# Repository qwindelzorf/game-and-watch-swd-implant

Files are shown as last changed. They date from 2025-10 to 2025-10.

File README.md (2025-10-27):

# Game & Watch SWD-Implant

A small [DAP-Link](https://github.com/ARMmbed/DAPLink) SWD programmer/debugger that fits insight a Nintendo® Game & Watch™ (2020/2021).

This is forked from [UlfWetzker/game-and-watch-swd-implant](https://github.com/UlfWetzker/game-and-watch-swd-implant), which has some issues and appears to be unmaintained.

## Mario (2020)

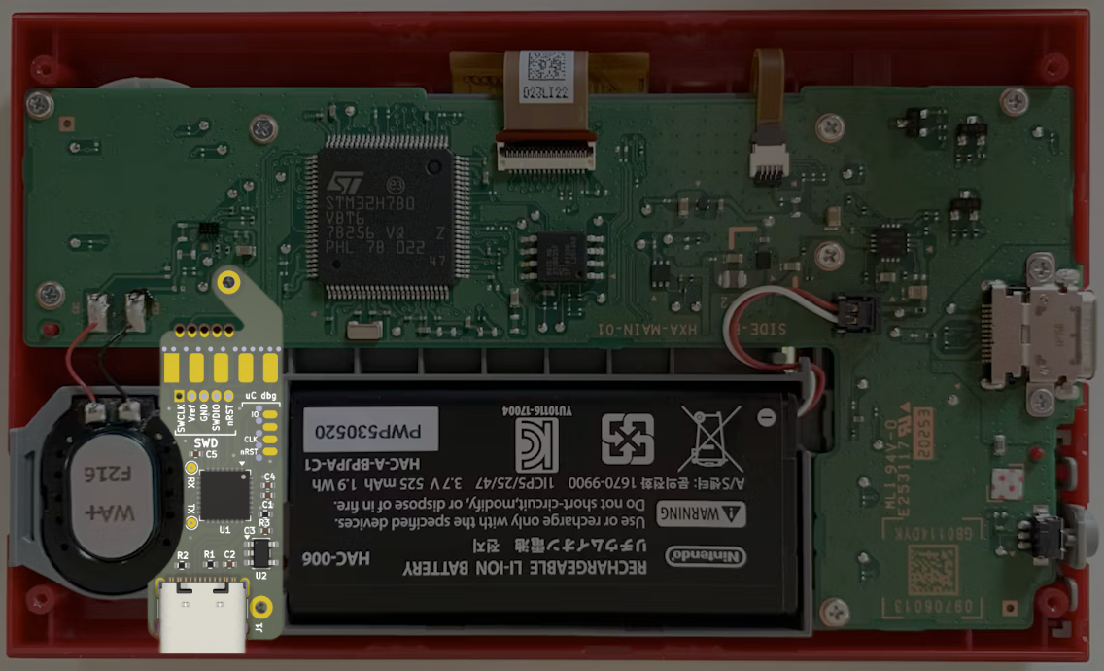
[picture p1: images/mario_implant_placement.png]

<p>
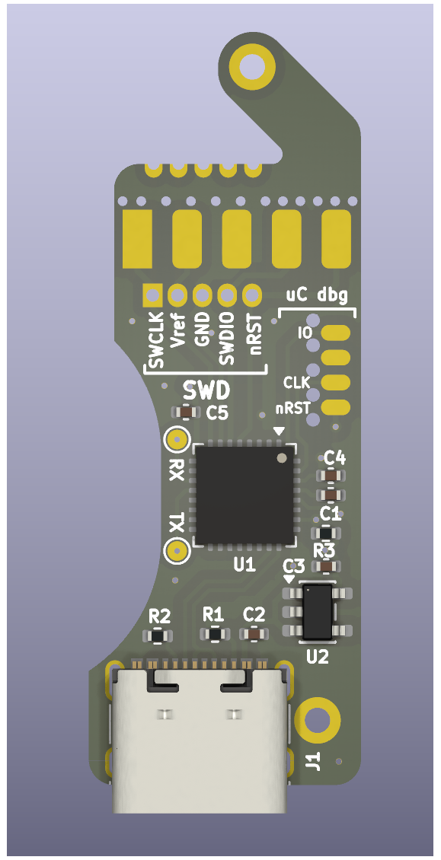
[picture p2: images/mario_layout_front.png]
Front
  
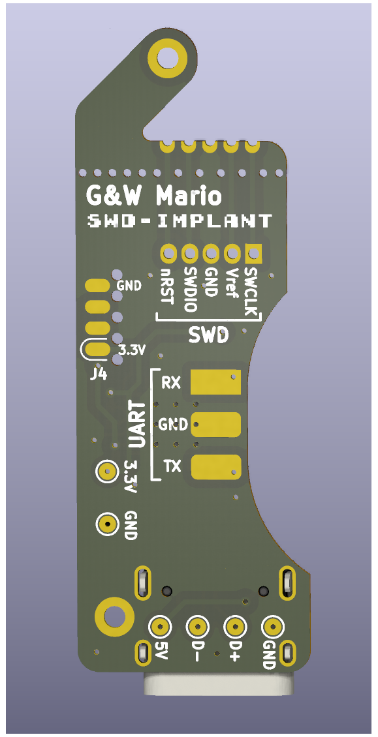
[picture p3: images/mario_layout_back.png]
Back
  
</p>

## Zelda (2021)

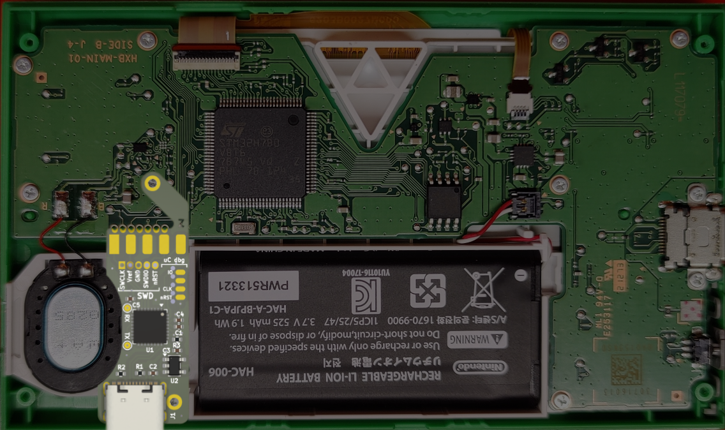
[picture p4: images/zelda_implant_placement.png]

<p>
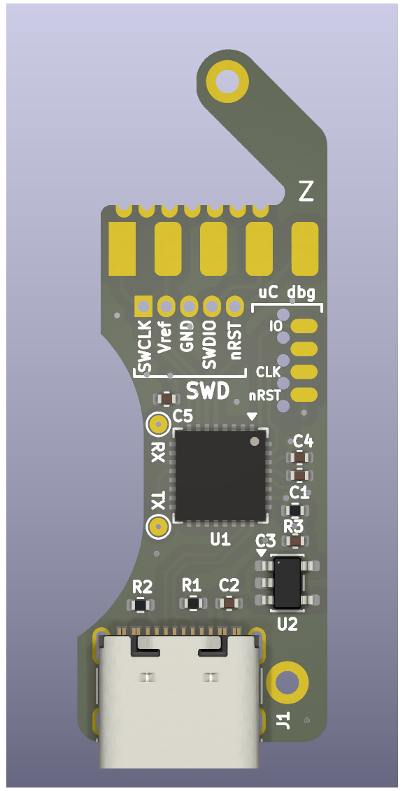
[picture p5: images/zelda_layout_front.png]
Front
  
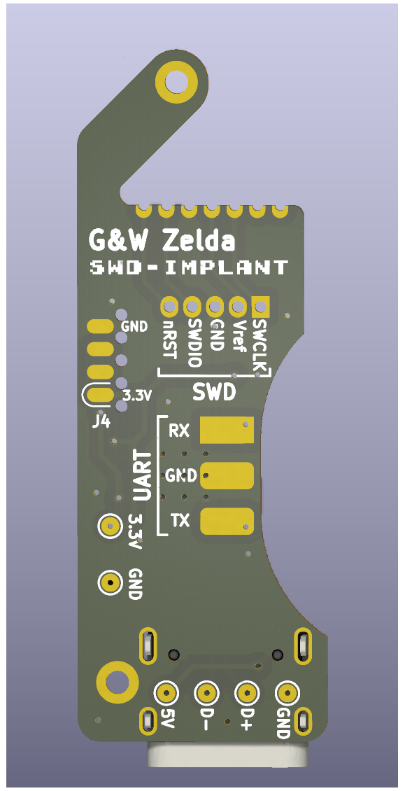
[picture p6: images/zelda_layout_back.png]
Back
  
</p>

## Implant Firmware

The implant board itself uses a [SAMD21](https://www.microchip.com/en-us/product/atsamd21g18) microcontroller, which is flashed with the [DAP-Link](https://github.com/ARMmbed/DAPLink) firmware. It is then able to act as a flasher for the G&W [STM32](https://www.st.com/en/microcontrollers-microprocessors/stm32-32-bit-arm-cortex-mcus.html) CPU. Flashing both the implant and the G&W is done using [OpenOCD](https://openocd.org/).

## G&W Firmware

The go-to firmware for these consoles is "RetroGo":
- [Original](https://github.com/kbeckmann/game-and-watch-retro-go): archived now
- [Zeus Fork](https://github.com/olderzeus/game-and-watch-retro-go): Adds more consoles
- [Sylverb Fork](https://github.com/sylverb/game-and-watch-retro-go): Adds yet more consoles, as well as support for LttP and SMW.

## Other Links

- SD Card mod: [link](https://github.com/sylverb/game-and-watch-retro-go-sd)
- Original homebrew work: [link](https://github.com/ghidraninja/game-and-watch-backup)
- Various firmware and utilities: [link](https://www.schuerewegen.tk/gnw/)
- A good tutorial on modding & flashing: [link](https://psxtools.de/forum/index.php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) (German)

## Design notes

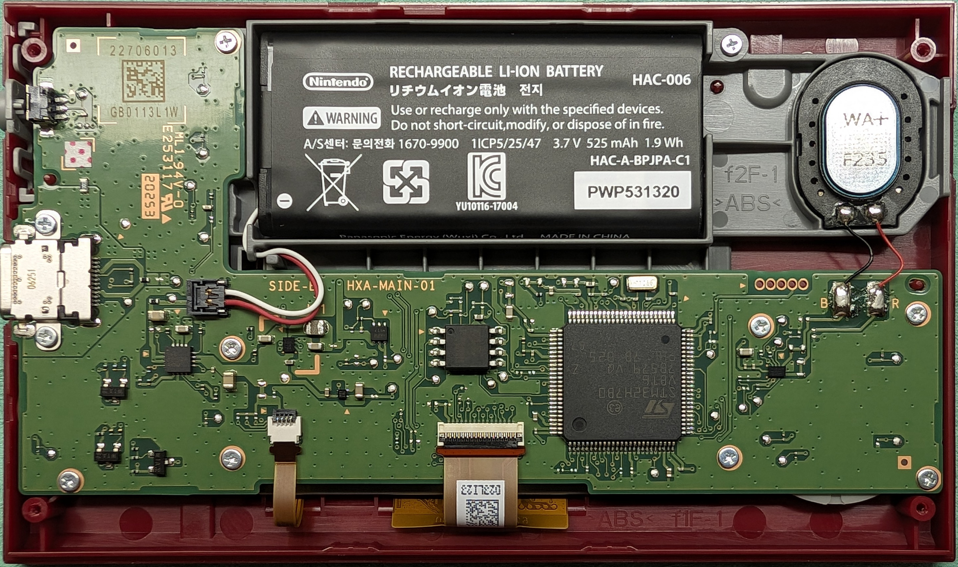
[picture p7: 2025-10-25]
images/mario_board.png

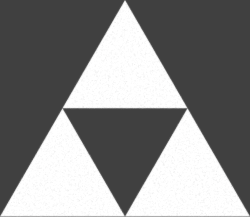
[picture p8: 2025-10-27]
triforce.png

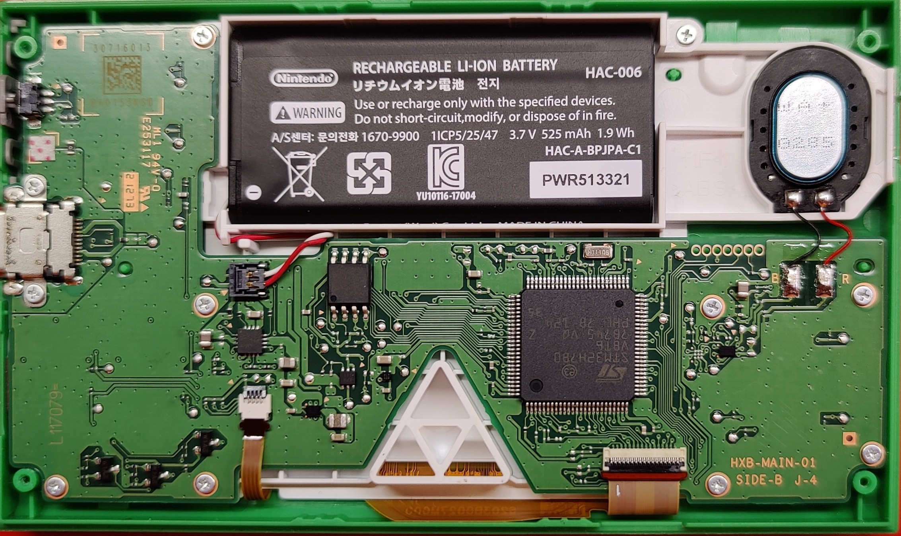
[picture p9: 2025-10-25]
images/zelda_board.png

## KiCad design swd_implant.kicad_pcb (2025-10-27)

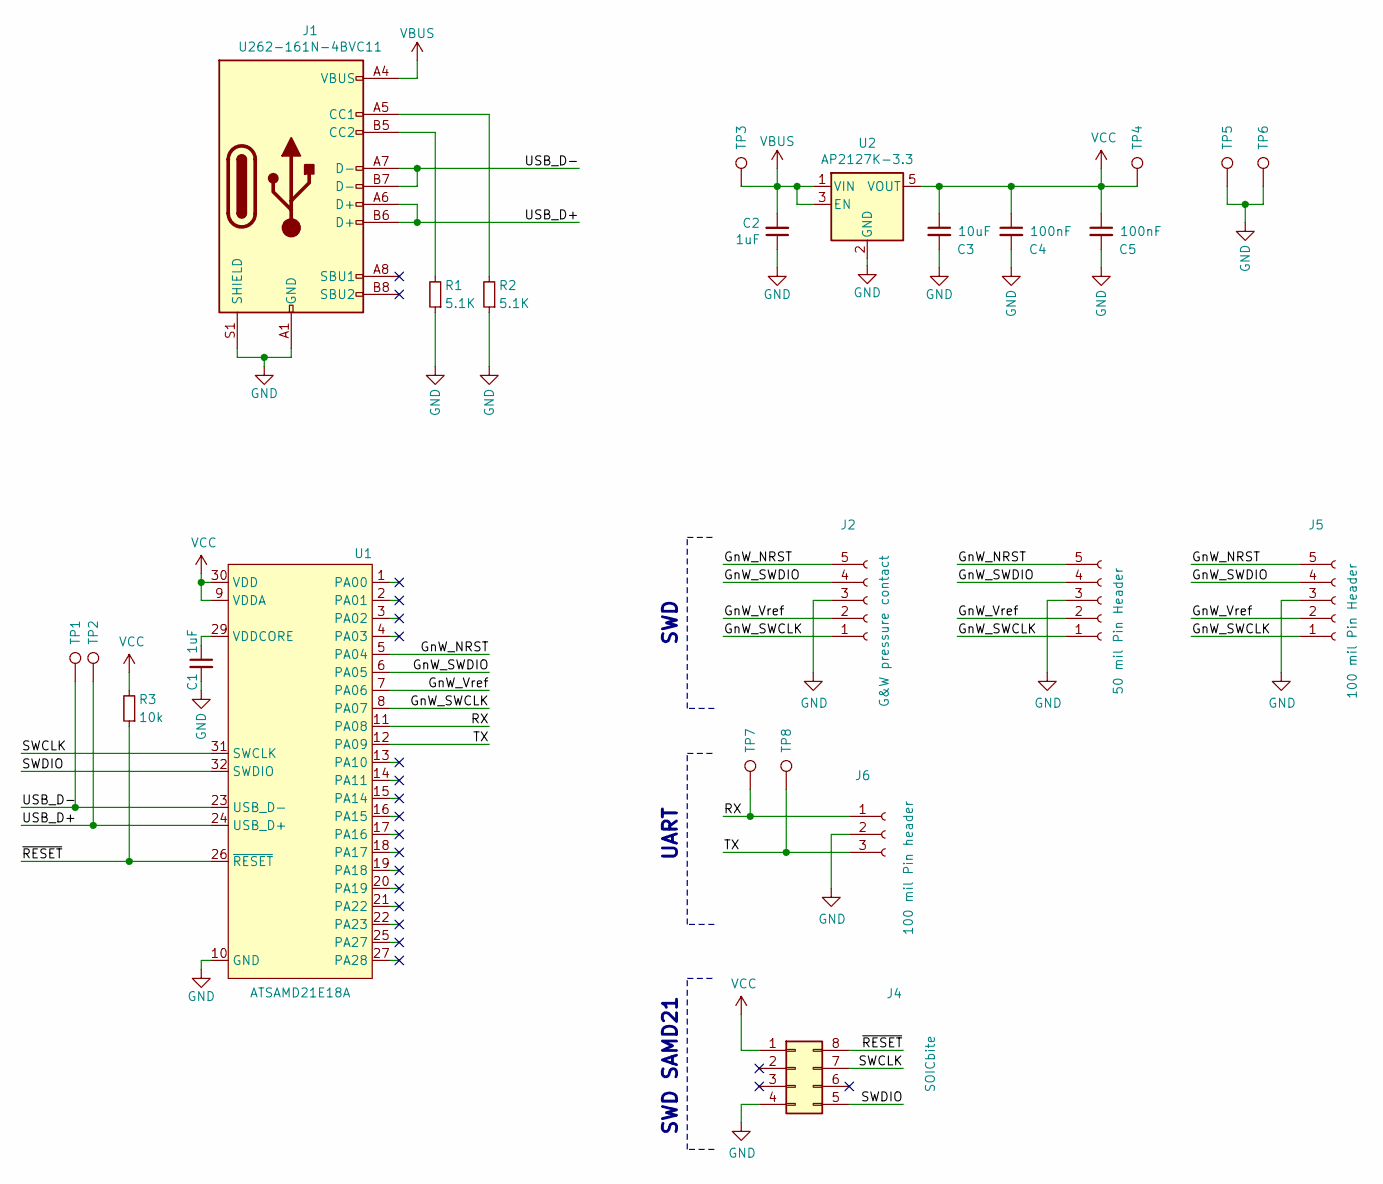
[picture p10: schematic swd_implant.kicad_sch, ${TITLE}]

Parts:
C1, C2: 1uF; C_0402_1005Metric; MFR.Part # CL05A105KA5NQNC; LCSC Part # C52923
C3: 10uF; C_0402_1005Metric; MFR.Part # CL05A106MQ5NUNC; LCSC Part # C15525
C4, C5: 100nF; C_0402_1005Metric; MFR.Part # CL05B104KO5NNNC; LCSC Part # C1525
J1: U262-161N-4BVC11; USB_C_Receptacle_XKB_U262-16XN-4BVC11; Mfr.Part # U262-161N-4BVC11; LCSC Part # C319148
J2: G&W pressure contact; GnW_SWD
J3: 50 mil Pin Header; PinHeader_1x05_P1.27mm_Vertical
J4: SOICbite; SOIC_clipProgSmall
J5: 100 mil Pin Header; PinHeader_1x05_P2.45mm_edge
J6: 100 mil Pin header; PinHeader_1x03_P2.45mm_edge
R1, R2: 5.1K; R_0402_1005Metric; MFR.Part # 0402WGF5101TCE; LCSC Part # C25905
R3: 10k; R_0402_1005Metric; MFR.Part # 0402WGJ0103TCE; LCSC Part # C25531
TP1, TP3, TP4, TP5, TP6, TP7, TP8: TP_USB_D+; TestPoint_Pad_D1.0mm
TP2: TP_USB_D-; TestPoint_Pad_D1.0mm
U1: ATSAMD21E18A; QFN-32-1EP_5x5mm_P0.5mm_EP3.6x3.6mm; MFR.Part # ATSAMD21E18A-MU; LCSC Part # C220692
U2: AP2127K-3.3; SOT-23-5; MFR.Part # AP2127K-3.3TRG1; LCSC Part # C156285

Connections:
/GnW_NRST: J2.5, J3.5, J5.5, U1.5 (PA04)
/GnW_SWCLK: J2.1, J3.1, J5.1, U1.8 (PA07)
/GnW_SWDIO: J2.4, J3.4, J5.4, U1.6 (PA05)
/GnW_Vref: J2.2, J3.2, J5.2, U1.7 (PA06)
/RX: J6.1, TP7.1, U1.11 (PA08)
/SWCLK: J4.7, U1.31 (SWCLK)
/SWDIO: J4.5, U1.32 (SWDIO)
/TX: J6.3, TP8.1, U1.12 (PA09)
/USB_D+: J1.A6 (D+), J1.B6 (D+), TP2.1, U1.24 (USB_D+)
/USB_D-: J1.A7 (D-), J1.B7 (D-), TP1.1, U1.23 (USB_D-)
/~RESET: J4.8, R3.1, U1.26 (~RESET)
GND: C1.2, C2.1, C3.2, C4.2, C5.2, J1.A1 (GND), J1.A12 (GND), J1.B1 (GND), J1.B12 (GND), J1.S1 (SHIELD), J2.3, J2.6, J2.7, J3.3, J4.4, J5.3, J6.2, R1.1, R2.1, TP5.1, TP6.1, U1.10 (GND), U1.28 (GND), U1.33, U2.2 (GND)
unnamed: J1.A5 (CC1), R2.2
unnamed: J1.B5 (CC2), R1.2
unnamed: C1.1, U1.29 (VDDCORE)
VBUS: C2.2, J1.A4 (VBUS), J1.A9 (VBUS), J1.B4 (VBUS), J1.B9 (VBUS), TP3.1, U2.1 (VIN), U2.3 (EN)
VCC: C3.1, C4.1, C5.1, J4.1, R3.2, TP4.1, U1.9 (VDDA), U1.30 (VDD), U2.5 (VOUT)

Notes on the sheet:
UART
SWD SAMD21
SWD

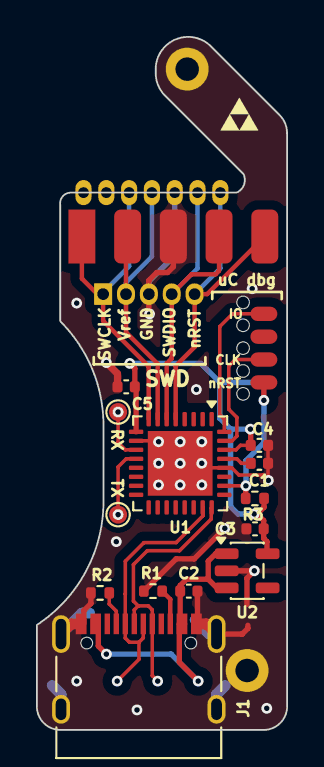
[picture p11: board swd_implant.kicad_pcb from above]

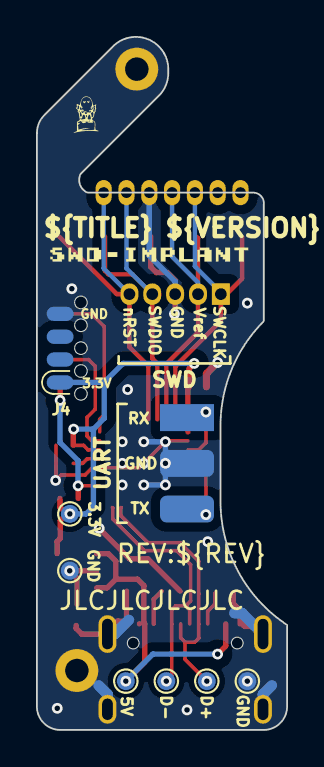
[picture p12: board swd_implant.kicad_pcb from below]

Board: 2 copper layers, 13.9 x 38.5 mm, 26 parts (10 on the bottom side), 17 nets.

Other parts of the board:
Q**: Qwindelzorf; qwindelzorf_1520
Ref**: Val**; name_logo

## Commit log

2025-10-25 New board outline & swd pinout fixes
    Changed the board outline to work with castellated edges, making it possible to
    solder down instead of just relying on pressure contact.
    Also fixed the inverted SWD pinout from upstream.
    [swd_implant.kicad_pcb, swd_implant.kicad_sch]
2025-10-25 Add Z marker to front of board
    This Z is to indicate that it is the "Zelda" variant of the implant
    board.
    [swd_implant.kicad_pcb]
2025-10-25 Add Zelda version of implant
    Just changed the board shape to fit the altered location of the SWD pins
    on that version.
    [swd_implant.kicad_pcb]
2025-10-25 Prep for fabrication
    [swd_implant.kicad_pcb, swd_implant.kicad_sch]
2025-10-26 Add LCSC part numbers
    [swd_implant.kicad_pcb, swd_implant.kicad_sch]
2025-10-27 Add logos
    [swd_implant.kicad_pcb]
